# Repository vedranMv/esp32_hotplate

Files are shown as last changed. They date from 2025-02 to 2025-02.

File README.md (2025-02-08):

ESP32 Reflow Hotplate
=====================

This repository contains electronics and an accompanying firmware for ESP32-powered hotplate from reflow soldering. The full project description can be found on [hackaday](https://hackaday.io/project/202351-reflow-soldering-hotplate).

Electronics schematics can be found in `electronics/` folder, together with a kicad project file and an accompanying PCB layout.

The remainder of folders belong to a pltaformio project for compiling the firmware. 

Features overview
-----------------

The list below contains the list of features supported by this project. Checked features are already implemented, the rest is pending development:

- [x] Heat element ON/OF
- [x] Plate temperature feedback
- [x] Internal temperature feedback
- [x] Input voltage feedback
- [x] Current power consumption
- [x] "Manual mode" - heat up and maintain given temperature
- [x] Configuration storage in non-volatile memory
- [ ] Timer indicating the time spent while heating up, reset when setpoint is reached to indicate the time spent at a setpoint
- [ ] "Profile mode" - follow a reflow profile for pre-programmed solder pastes
- [ ] Option to program a reflow profile via HMI
- Safety features:
  - [ ] Error if expecting to be heating up, but no temperature change is detected
  - [ ] Error if heating up for more 15 min
  - [ ] Error if temperature is 0

Software Design
---------------

To interact with the device, there's a user interface (HMI) consisting of OLED display and a rotary encoder with push button. Using push button gestures (click, double click and long press) it's possible to perform actions like edit/confirm/start/stop/etc, while rotary encoder can be used to scroll and increment data.

To make the best use of HMI, software is designed with the concept of 'applications'. Each application implements a device mode, or a behavior. For example, a manual mode is implemented as an app that allows the user to set manually a setpoint to which the hotplate heats up. User can select an active application, there can only be one active application at the time and the active application gets exclusive access to display and input. To see device stats (e.g. voltage, power, temperatures...), it's possible to change to stats app that shows all of that.

Apps interact with low level hardware via board support, that gives it access to analog and digital inputs/outputs or a configuration interface to load and save parameters from/to non-volatile storage.

Getting Started
---------------

This being a platformio project, getting started is realtively simple. If you have platformio already installed, it's enough to just clone this repository locally and open it in platformio. From there on, it's possible to build and upload the project to the target chip.

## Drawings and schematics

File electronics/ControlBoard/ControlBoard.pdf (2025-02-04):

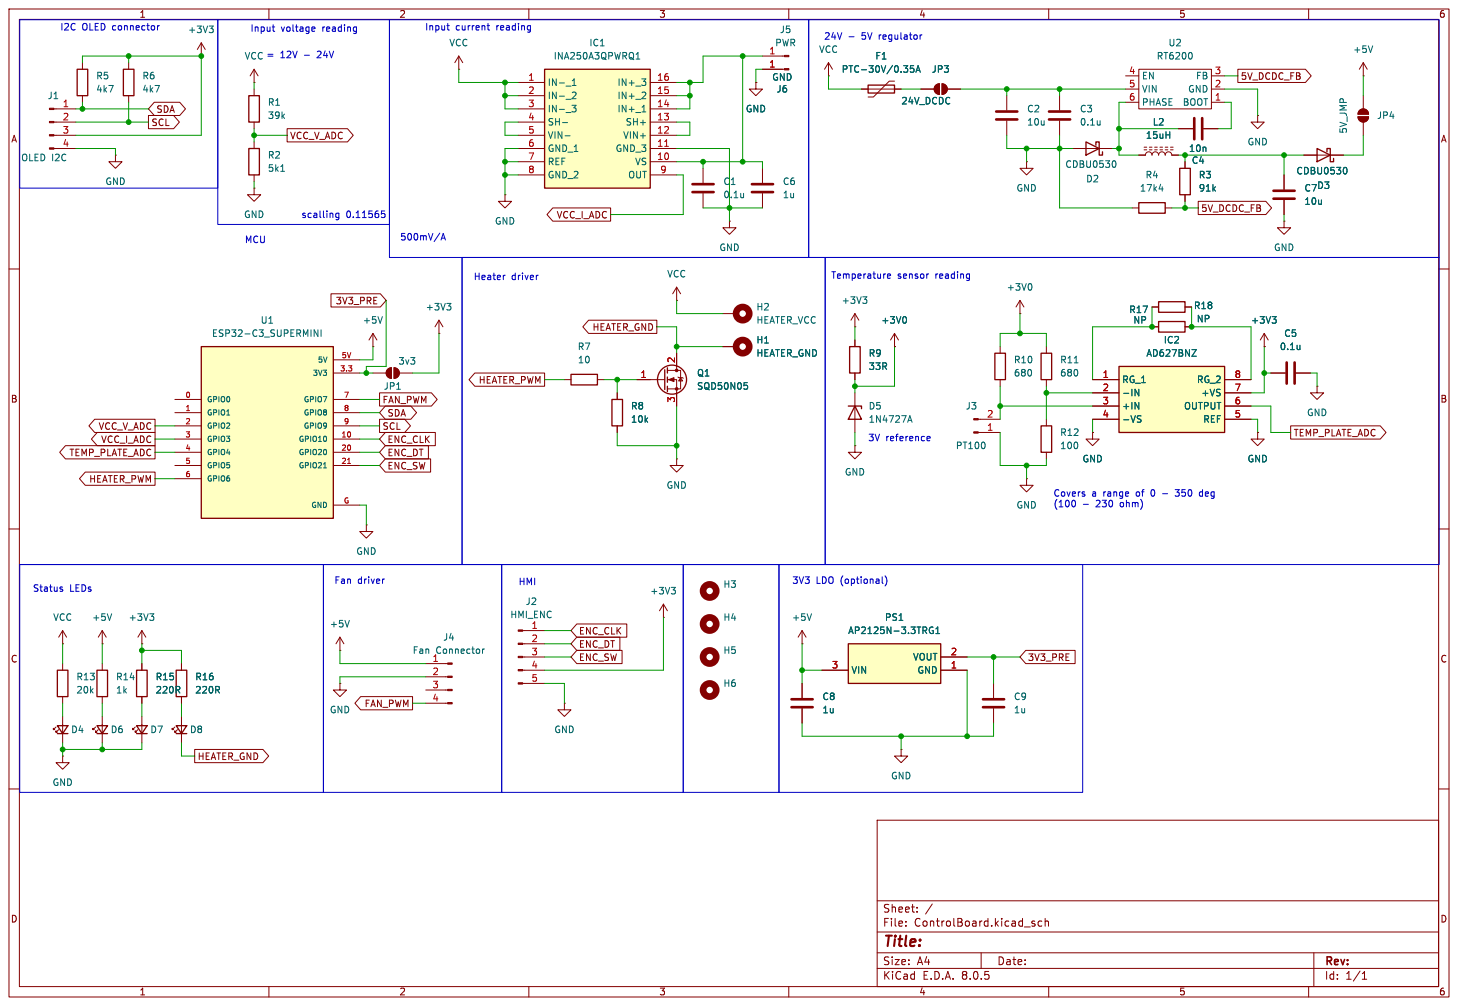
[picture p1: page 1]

Id: 1/1 Title: File: ControlBoard.kicad_sch Sheet: /

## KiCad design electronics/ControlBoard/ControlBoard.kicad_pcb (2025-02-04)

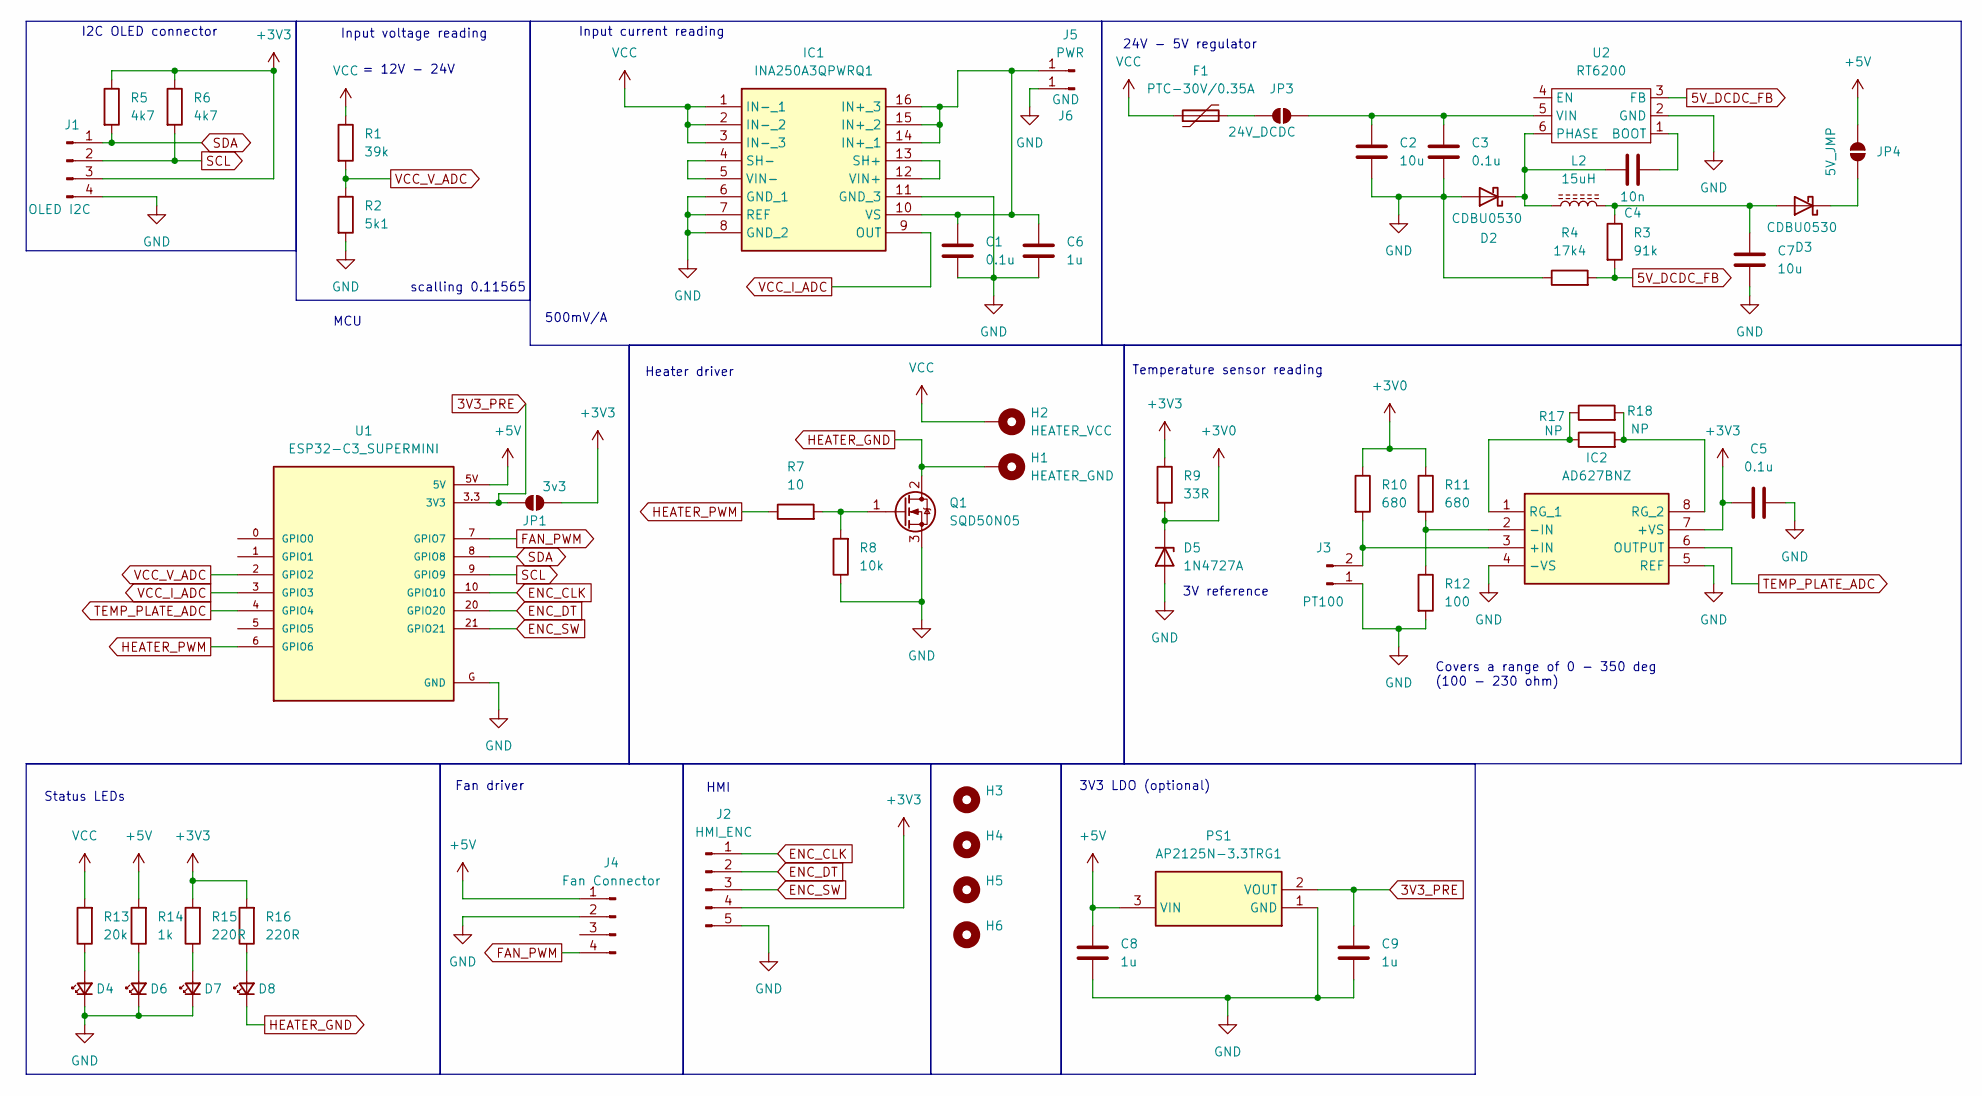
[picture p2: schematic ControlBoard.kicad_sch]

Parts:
C1, C5: 0.1u; R_0603_1608Metric_Pad0.98x0.95mm_HandSolder
C2: 10u; C_1210_3225Metric
C3: 0.1u; C_0603_1608Metric_Pad1.08x0.95mm_HandSolder
C4: 10n; C_0603_1608Metric_Pad1.08x0.95mm_HandSolder
C6, C8, C9: 1u; R_0603_1608Metric_Pad0.98x0.95mm_HandSolder
C7: 10u; C_0805_2012Metric_Pad1.18x1.45mm_HandSolder
D2, D3: CDBU0530; D_0603_1608Metric_Pad1.05x0.95mm_HandSolder
D4, D6, D7, D8: LED_0805_2012Metric_Pad1.15x1.40mm_HandSolder
D5: 1N4727A; D_DO-41_SOD81_P10.16mm_Horizontal
F1: PTC-30V/0.35A; Fuse_1206_3216Metric
H1: HEATER_GND; MountingHole_3.2mm_M3_DIN965_Pad
H2: HEATER_VCC; MountingHole_3.2mm_M3_DIN965_Pad
H3, H4, H5, H6: MountingHole; MountingHole_3.2mm_M3_ISO7380
IC1: INA250A3QPWRQ1; SOP65P640X120-16N; Manufacturer_Part_Number INA250A3QPWRQ1
IC2: AD627BNZ; DIP794W56P254L959H533Q8N; Manufacturer_Part_Number AD627BNZ
J1: OLED I2C; PinHeader_1x04_P2.54mm_Vertical
J2: HMI_ENC; PinHeader_1x05_P2.54mm_Vertical
J3: PT100; PinHeader_1x02_P2.54mm_Vertical
J4: Fan Connector; PinHeader_1x04_P2.54mm_Vertical
J5: PWR; TestPoint_Pad_4.0x4.0mm
J6: GND; TestPoint_Pad_4.0x4.0mm
JP1: 3v3; SolderJumper-2_P1.3mm_Open_RoundedPad1.0x1.5mm
JP3: 24V_DCDC; SolderJumper-2_P1.3mm_Open_RoundedPad1.0x1.5mm
JP4: 5V_JMP; SolderJumper-2_P1.3mm_Open_RoundedPad1.0x1.5mm
L2: 15uH; SRR4828A151M
PS1: AP2125N-3.3TRG1; SOT95P282X145-3N; Manufacturer_Part_Number AP2125N-3.3TRG1
Q1: SQD50N05; TO-252-2
R1: 39k; R_0805_2012Metric
R2: 5k1; R_0805_2012Metric
R3: 91k; R_0603_1608Metric_Pad0.98x0.95mm_HandSolder
R4: 17k4; R_0603_1608Metric_Pad0.98x0.95mm_HandSolder
R5, R6: 4k7; R_0805_2012Metric
R7: 10; R_0805_2012Metric
R8: 10k; R_0805_2012Metric
R9: 33R; R_0805_2012Metric
R10, R11: 680; R_0805_2012Metric
R12: 100; R_0805_2012Metric
R13: 20k; R_0603_1608Metric_Pad0.98x0.95mm_HandSolder
R14: 1k; R_0603_1608Metric_Pad0.98x0.95mm_HandSolder
R15, R16: 220R; R_0603_1608Metric_Pad0.98x0.95mm_HandSolder
R17, R18: NP; R_0805_2012Metric
U1: ESP32-C3_SUPERMINI; MODULE_ESP32-C3_SUPERMINI
U2: RT6200; SOT-23-6_Handsoldering

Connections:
3V3_PRE: C9.1, JP1.2 (B), PS1.2 (VOUT), U1.3.3 (3V3)
5V_DCDC_FB: R3.2, R4.2, U2.3 (FB)
+3V0: D5.1 (K), R9.2, R10.1, R11.1
+3V3: C5.2, IC2.7 (+VS), J1.3, J2.4, JP1.1 (A), R5.1, R6.1, R9.1, R15.2, R16.2
+5V: C8.1, J4.1, JP4.2 (B), PS1.3 (VIN), R14.2, U1.5V
ENC_CLK: J2.1, U1.10 (GPIO10)
ENC_DT: J2.2, U1.20 (GPIO20)
ENC_SW: J2.3, U1.21 (GPIO21)
FAN_PWM: J4.4, U1.7 (GPIO7)
GND: C1.1, C2.1, C3.1, C5.1, C6.1, C7.1, C8.2, C9.2, D2.2 (A), D4.1 (K), D5.2 (A), D6.1 (K), D7.1 (K), IC1.6 (GND_1), IC1.7 (REF), IC1.8 (GND_2), IC1.11 (GND_3), IC2.4 (-VS), IC2.5 (REF), J1.4, J2.5, J3.1, J4.2, J6.1, PS1.1 (GND), Q1.3 (S), R2.2, R4.1, R8.1, R12.2, U1.G (GND), U2.2 (GND)
HEATER_GND: D8.1 (K), H1.1, Q1.2 (D)
HEATER_PWM: R7.1, U1.6 (GPIO6)
unnamed: C4.1, D2.1 (K), L2.1, U2.6 (PHASE)
unnamed: C7.2, D3.2 (A), L2.2, R3.1
unnamed: D3.1 (K), JP4.1 (A)
unnamed: D4.2 (A), R13.1
unnamed: D6.2 (A), R14.1
unnamed: D7.2 (A), R15.1
unnamed: D8.2 (A), R16.1
unnamed: C1.2, C6.2, IC1.10 (VS), IC1.14 (IN+_1), IC1.15 (IN+_2), IC1.16 (IN+_3), J5.1
unnamed: IC1.12 (VIN+), IC1.13 (SH+)
unnamed: IC1.4 (SH-), IC1.5 (VIN-)
unnamed: IC2.3 (+IN), J3.2, R10.2
unnamed: IC2.2 (-IN), R11.2, R12.1
unnamed: IC2.1 (RG_1), R17.1, R18.1
unnamed: IC2.8 (RG_2), R17.2, R18.2
unnamed: F1.2, JP3.1 (A)
unnamed: C2.2, C3.2, JP3.2 (B), U2.5 (VIN)
unnamed: Q1.1 (G), R7.2, R8.2
unnamed: C4.2, U2.1 (BOOT)
SCL: J1.2, R6.2, U1.9 (GPIO9)
SDA: J1.1, R5.2, U1.8 (GPIO8)
TEMP_PLATE_ADC: IC2.6 (OUTPUT), U1.4 (GPIO4)
VCC: F1.1, H2.1, IC1.1 (IN-_1), IC1.2 (IN-_2), IC1.3 (IN-_3), R1.1, R13.2
VCC_I_ADC: IC1.9 (OUT), U1.3 (GPIO3)
VCC_V_ADC: R1.2, R2.1, U1.2 (GPIO2)

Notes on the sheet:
I2C OLED connector
Fan driver
Input current reading
Temperature sensor reading
HMI
= 12V - 24V
Input voltage reading
Status LEDs
3V reference
3V3 LDO (optional)
500mV/A
Heater driver
scalling 0.11565
MCU
Covers a range of 0 - 350 deg (100 - 230 ohm)
24V - 5V regulator

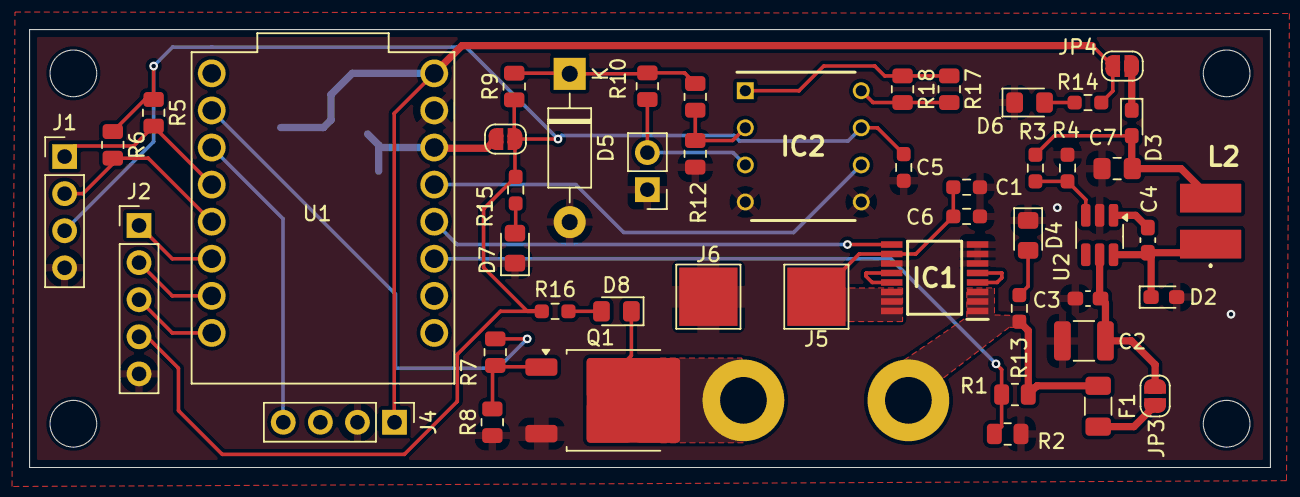
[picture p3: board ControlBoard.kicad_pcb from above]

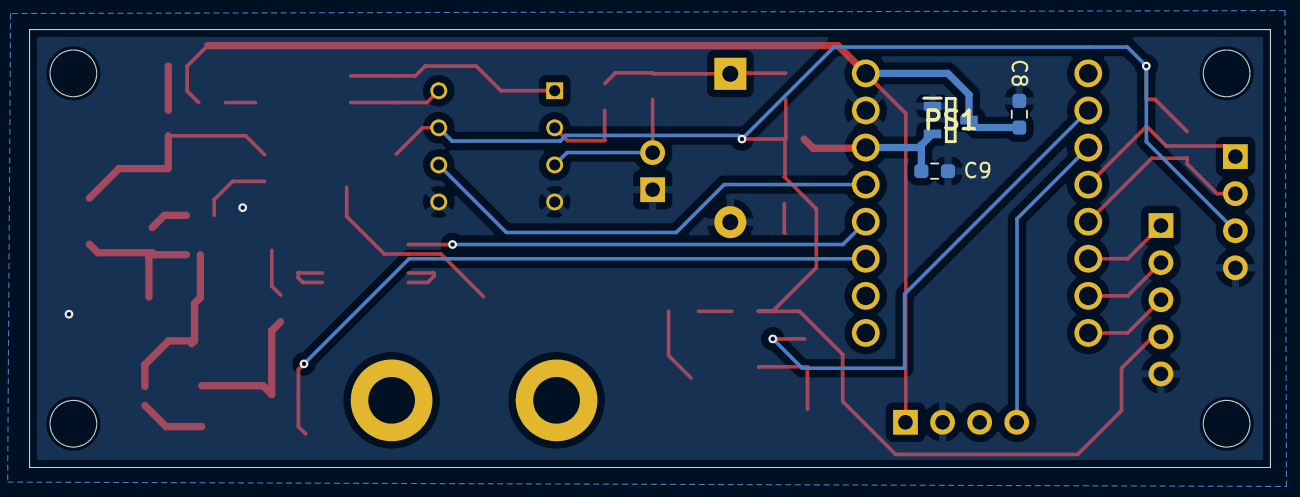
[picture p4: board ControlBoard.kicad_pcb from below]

Board: 2 copper layers, 85.0 x 30.0 mm, 57 parts (3 on the bottom side), 36 nets.

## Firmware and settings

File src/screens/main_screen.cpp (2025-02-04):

#include "screens/main_screen.hpp"

#include "bsp.hpp"

MainScreen::MainScreen() 
{
    _set_state(State::Cooling);
};

void MainScreen::render(Adafruit_SSD1306 &display)
{
    auto T = bsp::analog::get_plate_temp_C();

    run_temp_regulation();

    if (isnan(T))
    {
        return;
    }

    display.setTextColor(SSD1306_WHITE);

    display.setTextSize(1);
    int16_t x, y;
    uint16_t w, h;
    display.getTextBounds("[Manual Mode]", 0, 0, &x, &y, &w, &h);
    display.setCursor(128-w,0);
    display.println("[Manual Mode]");
    display.setCursor(0,h);

    display.setTextSize(2);
    display.printf("%3d/%3d %cC\n", T, _temp_setpoint,247);
    display.setTextSize(1);

    float input_i_a = bsp::analog::get_amp_input_A();
    float input_v_v = bsp::analog::get_volt_input_V();
    
    if (_state_edit())
        display.printf("Edit setpoint\n");
    else if (_state_cooling())
        display.printf("Cooling\n");
    else if (_state_heating())
    {
        display.printf("Heating @ %01.1fW\n", input_v_v*input_i_a);
    }

    // Run fan if we're trying to cool down
    if (_state_cooling())
    {
        if (T > 40)
            bsp::output::set_fan_duty(100);
        else
            bsp::output::set_fan_duty(0);
    }
}

void MainScreen::input_callback(Button::eButtonStates btn_state, int16_t enc_increment)
{
    if (_state_edit())
    {
        _temp_setpoint = _temp_setpoint-_last_enc_increment;
        if (_temp_setpoint > 250)
        {
            _temp_setpoint = 250;
        }
        if (_temp_setpoint < 20)
        {
            _temp_setpoint = 20;
        }
    }

    switch (btn_state)
    {
    case Button::Clicked:
        Serial.println("Clicked");
        if (_state_edit())
        {
            _set_state(State::Cooling);
        }
        else 
        {
            _set_state(State::Editing);
        }
        break;
    case Button::DoubleClicked:
        Serial.println("Double Clicked");
        break;
    case Button::Held:
        break;
    case Button::LongPressRepeat:
        Serial.println("Long press");
        if (!_state_heating()){
            _set_state(State::Heating);
        }
        else if (!_state_cooling())
        {
            _set_state(State::Cooling);
        }
        
        break;
    case Button::Released:
        Serial.println("Released");
        break;
    default:
        // no output for "Open" or "Closed" to not spam the console.
        break;
    }

    _last_btn_state = btn_state; 
    _last_enc_increment = enc_increment; 
}

void MainScreen::run_temp_regulation()
{
    auto T = bsp::analog::get_plate_temp_C();
    auto temp_delta = T - _temp_setpoint;

    // Only run regulation when in heating mode
    if (!_state_heating())
    {
        return;
    }
       

    if (temp_delta >= 1 && bsp::output::get_heater_on())
    {
        bsp::output::set_heater_state(0);
    }

    if (temp_delta <= -1 && !bsp::output::get_heater_on())
    {
        bsp::output::set_heater_state(1);
    }

}

bool MainScreen::_state_edit() { return _state == State::Editing; }
bool MainScreen::_state_heating() { return _state == State::Heating; }
bool MainScreen::_state_cooling() { return _state == State::Cooling; }

void MainScreen::_set_state(State state)
{
    if (state == State::Cooling || state == State::Editing)
    {
        digitalWrite(GPIO_NUM_6, 0);
        
    }

    if (state == State::Heating)
    {
        digitalWrite(GPIO_NUM_6, 1);
    }

    _state = state;
}

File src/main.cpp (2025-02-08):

#include <Arduino.h>
#include "ESP32_C3_TimerInterrupt.h"

#include <EEPROM.h>
#include "bsp.hpp"
#include "hmi.hpp"
#include "apps/manual.hpp"
#include "apps/stats.hpp"
#include "apps/splash_screen.hpp"

ESP32Timer ITimer0(0);

void setup() {
    Serial.begin(115200);
    
    bsp::init();
    auto& hmi = HMI::get();

    if (ITimer0.attachInterruptInterval(1000, [](void*)-> bool { HMI::get().isr_timer_callback(); return true;}))
	{
		Serial.print(F("Starting  ITimer0 OK, millis() = "));
		Serial.println(millis());
	}
	else
		Serial.println(F("Can't set ITimer0. Select another freq. or timer"));

    SplashScreen splash;
    splash.render(HMI::get().hw());

    hmi.register_screen(std::move(std::make_unique<ManualMode>()));
    hmi.register_screen(std::move(std::make_unique<Stats>()));
}

void loop() {
    HMI::get().update();

    delay(500);
}

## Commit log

2025-02-08 Replace screen with app
    [hmi.cpp, main.cpp, manual.cpp]
2025-02-08 Remove pin definitions from a header
